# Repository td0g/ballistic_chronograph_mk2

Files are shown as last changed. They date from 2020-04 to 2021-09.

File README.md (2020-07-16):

# ballistic_chronograph_mk2

The Ballistic Chronograph MK2 is based on my earlier model, but has been redesigned for ease of assembly.  For more information, please see td0g.ca.

## Files

### LightGateSensor

The PCB design for the sensors used in the chronograph.

### STL

3D print files for the chronograph.  Make sure to print the correct files as there are options:

* Slit Width: 2mm or 3mm

* Sensor Height: Single or Double

* Sensor Width: 125mm or 100mm

### Arduino Firmware

* BallistiChronographBasic - Very basic use, can support Serial connection or LCD display.

* BallistiChronographCompound - Allows up to 6 sensors, Serial connection only.

* BallisticChronographLCD - Standalone firmware with flash triggering capability for Arduino with an LCD keypad shield.

### Assembly Manual

A complete assembly manual for constructing your own ballistic chronograph.

## License

Documentation and STL files are licensed under a [Creative Commons Attribution 4.0 International License](https://creativecommons.org/licenses/by/4.0/)

Software is licensed under a [GNU GPL v3 License](https://www.gnu.org/licenses/gpl-3.0.txt)

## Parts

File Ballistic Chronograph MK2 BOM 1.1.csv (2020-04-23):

Notes
 | Digikey is my preferred electronics vendor (Good prices, cheapest shipping, ships from Winnipeg) |  |  |  |  | Last updated 2020-04-22
 | Mouser and others are good as well. Same with eBay/Alibaba/Bangood.
 | Spool3D is my preferred hardware vendor
Part# | Manufacturer Model | Description | Qty (Single / Double Sensor Height) | Suggested Vendor | Vendor Part # | Price Per (CAD, At time of original manufacture) | Link
1 | TSHF5410 | LED (emitter) | 8 / 16 | Digikey | TSHF5410/751-1211-ND | $1.04 | https://www.digikey.ca/product-detail/en/vishay-semiconductor-opto-division/TSHF5410/751-1211-ND/1681346
2 | LG0 | Light Gate Sensors | 2 / 4 | Tindie |  | $17.70 | tindie.com
3 | Arduino Uno | Arduino | 1 | Amazon |  | $14.00 | https://www.amazon.ca/Arduino-Development-Microcontroller-Atmega328p-Straight/dp/B07M87FYPD
4 | LCD Keypad Shield | Arduino UI Shield | 1 | Amazon |  | $11.20 | https://www.amazon.ca/SODIAL-Keypad-Shield-Backlight-Arduino/dp/B00OPO2W6M
5 | 2020 Aluminum Extrusion |  | ~1m (depending on your desired size) | Spool3D |  | $12.00 | https://spool3d.ca/2020-aluminum-extrusion/
6 | PLA Plus / PETG Filament | 3D print material | ~0.5kg | Spool3D |  | $15.00 | https://spool3d.ca
7 | M2 x 8mm Screws | Fasteners | 18 / 22 |  |  | -
8 | M3 x 8mm Screws | Fasteners | 4 |  |  | -
9 | M4 x 10mm Screws | Fasteners | 12 |  |  | -
10 | M4 T-Slot Nuts | Fasteners | 12 |  |  | -
11 | Prototyping Female-Female Jumper Wires | Wiring | 10 |  |  | -
12 | 22-Gauge Wire | Wiring | ~3m |  |  | -
13 | LED Current Limiting Resistors (Please see assembly manual, appendix A) |  |  |  |  | -
 |  |  |  |  | Total Price (Single Sensor Height) | $95.92 | CAD
 |  |  |  |  | Total Price (Double Sensor Height) | $139.64 | CAD

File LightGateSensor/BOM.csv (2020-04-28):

Index | Quantity | Digikey Part Number | LCSC Part Number | Manufacturer Part Number | Description | Value | Footprint | Designator
1 | 1 | 296-12686-1-ND | C9846 | TPS61041DBVR | IC LED DRIVER RGLTR DIM SOT23-5 |  | SOT-23-5 | U2
2 | 1 | LM339MX/NOPBCT-ND | C89046 |  | IC COMPARATOR QUAD LO PWR 14SOIC |  | SOIC-14_150mil | U1
3 | 1 |  | C104352 |  | RES 470K 1/8W | 470K | 805 | R10
4 | 2 | 587-4963-1-ND | C342803 | UMK212BB7225MG-T | CAP CER 2.2UF 50V X7R 0805 | 2.2UF | 805 | C6 C7
5 | 4 |  | C76645 |  | CAP CER 1UF 50V X7R 0805 | 1UF | 805 | C1 C2 C3 C4
6 | 1 |  | C253451 |  | RES 22K 1/8W | 22K | 805 | R11
7 | 5 | A126361CT-ND | C156145 | CRG0805F330K | RES SMD 330K OHM 1% 1/8W 0805 | 330K | 805 | R2 R4 R6 R8
8 | 1 | 478-7806-1-ND | C455082 | SD1206S040S2R0 | Diode |  | SOD-123 | D5
9 | 4 | RMCF0805JT47K0CT-ND | C304417 | RMCF0805JT47K0 | RES 47K OHM 5% 1/8W 0805 | 47K | 805 | R1 R3 R5 R7
10 | 1 | 587-2985-1-ND | C106836 | TMK212BBJ106KG-T | CAP CER 10UF 16V X5R 0805 | 10UF | 805 | C5
11 | 1 | 399-7874-1-ND | C162300 | C0603C220J1GACTU | CAP CER 22PF 100V C0G/NP0 0603 | 22PF | 805 | C8
12 | 1 | 587-1613-1-ND | C223252 | CBC2518T100M | FIXED IND 10UH 680MA 468 MOHM | 22UH | 805 | L2
13 | 1 | CMP321609UD4R7MT | C139250 |  | FIXED IND 4.7UH 700mA | 4.7UH | 1206 | L1
14 | 4 | 1993-1049-ND |  | PT6KV-502A2020 | 5K Pot
15 | 4 | 160-1987-ND |  | LTR-323DB | SENSOR PHOTODIODE 900NM RADIAL
16 | 1 |  |  | lg0 | PCB

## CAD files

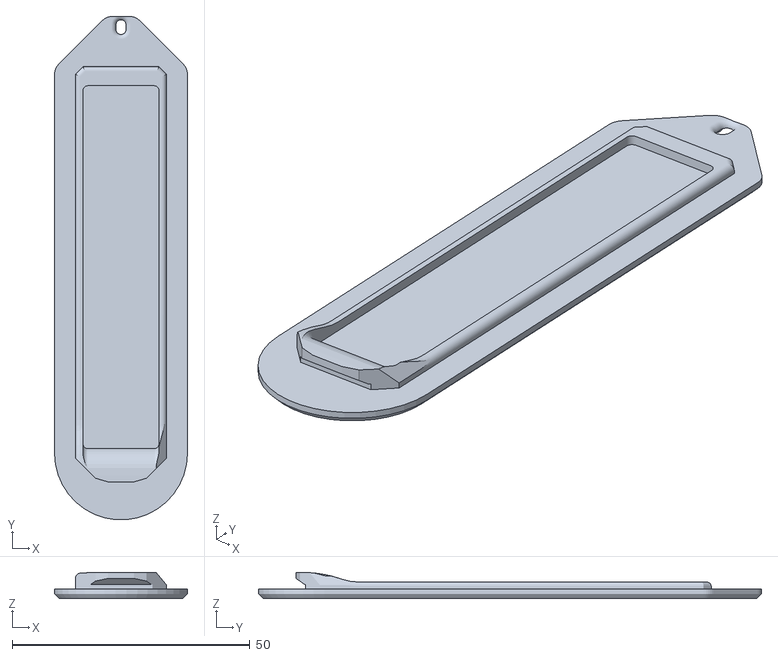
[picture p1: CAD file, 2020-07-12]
STL/EmitterCover_double.STL
28.0 x 106.0 x 5.50

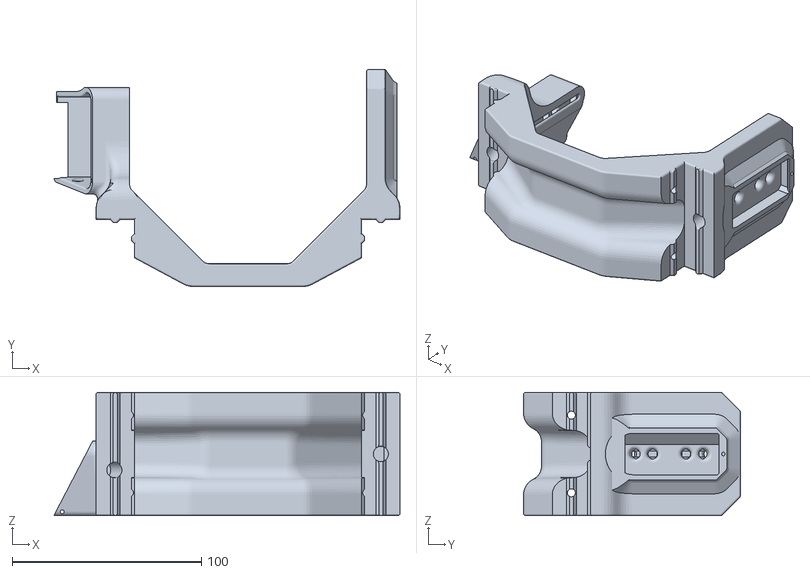
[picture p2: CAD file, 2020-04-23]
STL/Gate_single_3mmSlit_125mmWidth.STL
182.6 x 114.5 x 65.0

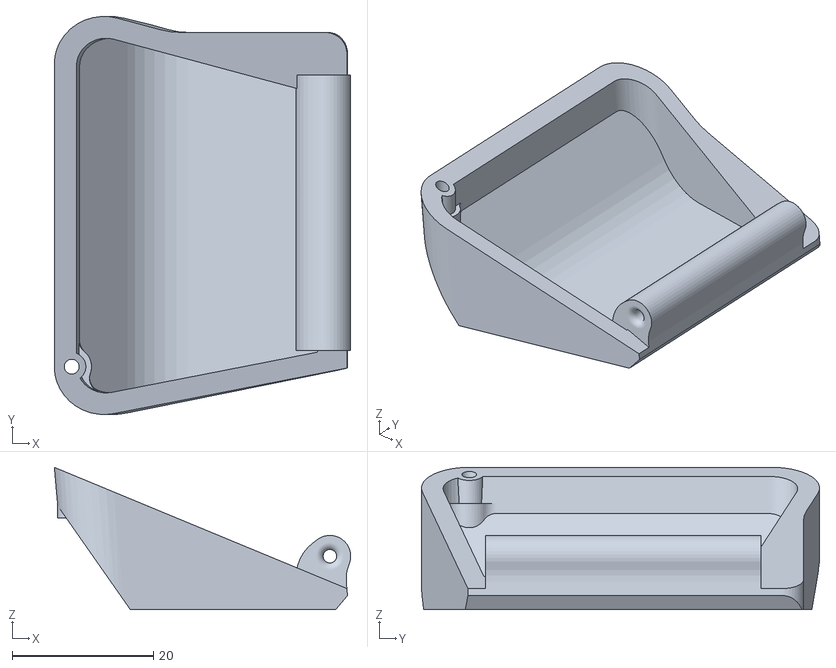
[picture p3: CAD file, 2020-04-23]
STL/SensorCover_single.STL
41.9 x 56.3 x 20.1

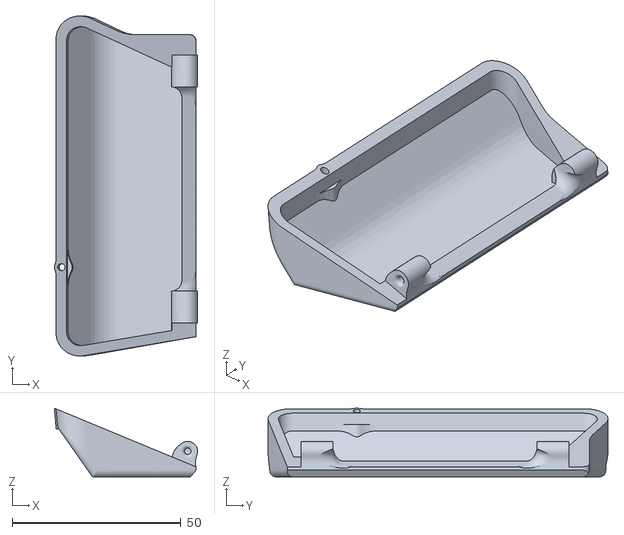
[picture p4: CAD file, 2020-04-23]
STL/SensorCover_double.STL
42.5 x 100.7 x 20.4

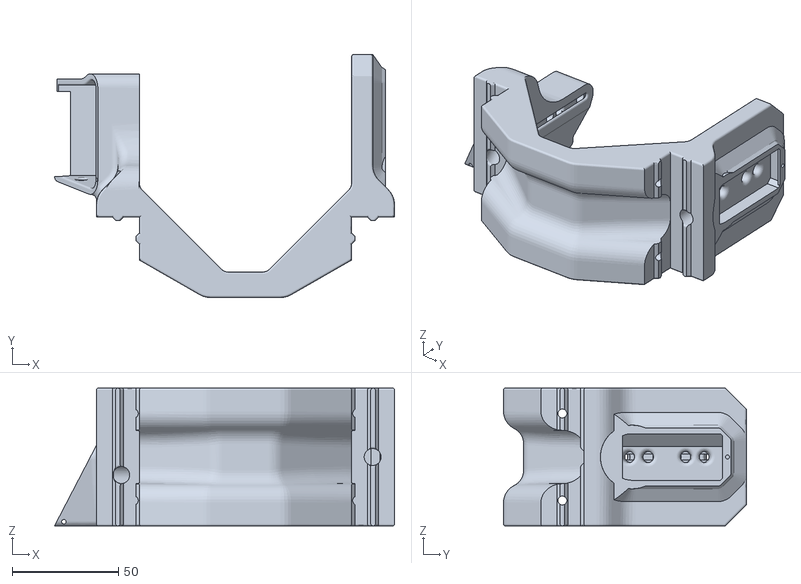
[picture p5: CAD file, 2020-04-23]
STL/Gate_single_3mmSlit_100mmWidth.STL
160.2 x 114.5 x 65.0

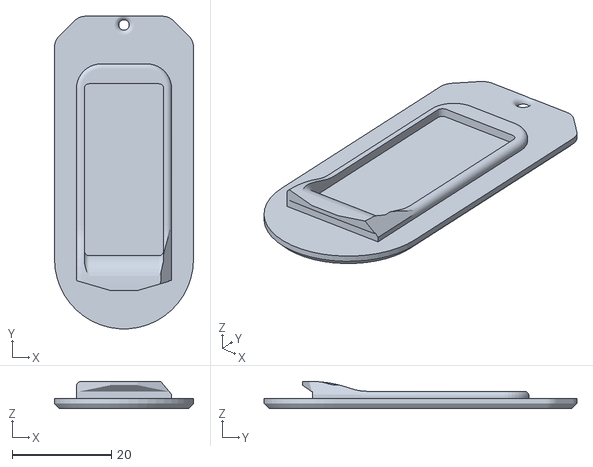
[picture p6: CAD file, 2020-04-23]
STL/EmitterCover_single.STL
28.0 x 63.0 x 5.50

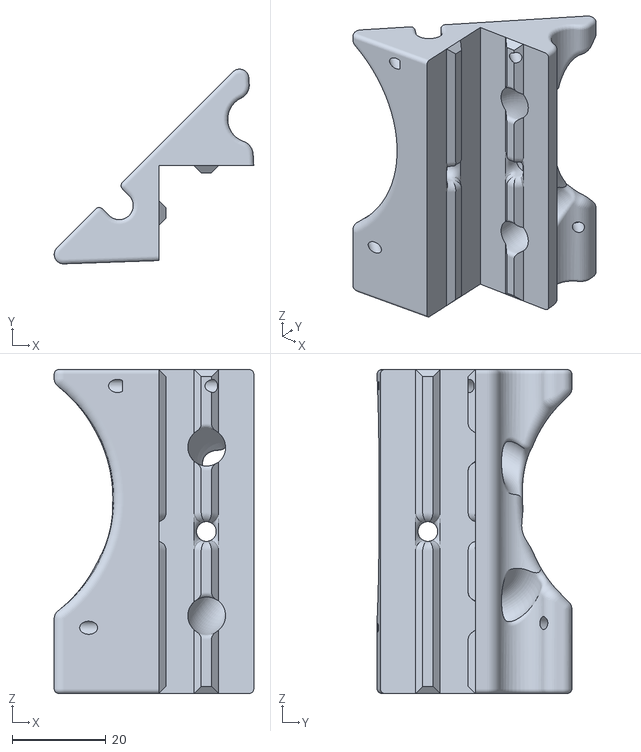
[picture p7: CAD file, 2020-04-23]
STL/Arduino Mount.STL
42.5 x 41.5 x 69.0

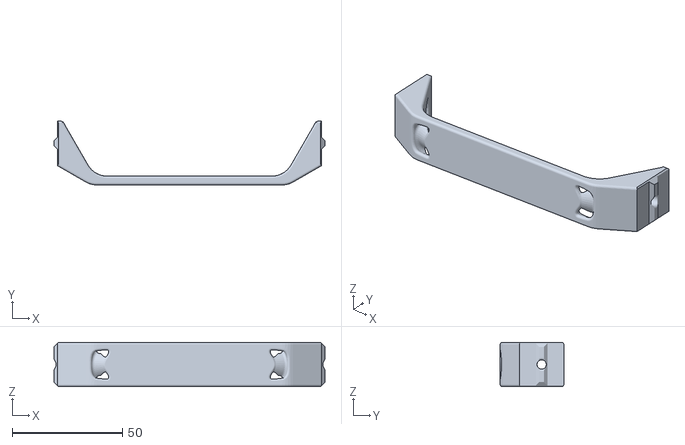
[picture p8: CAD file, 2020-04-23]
STL/Crossmember.STL
123.0 x 29.0 x 20.0

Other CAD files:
STL/Gate_single_2mmSlit_125mmWidth.STL
STL/Gate_single_2mmSlit_100mmWidth.STL

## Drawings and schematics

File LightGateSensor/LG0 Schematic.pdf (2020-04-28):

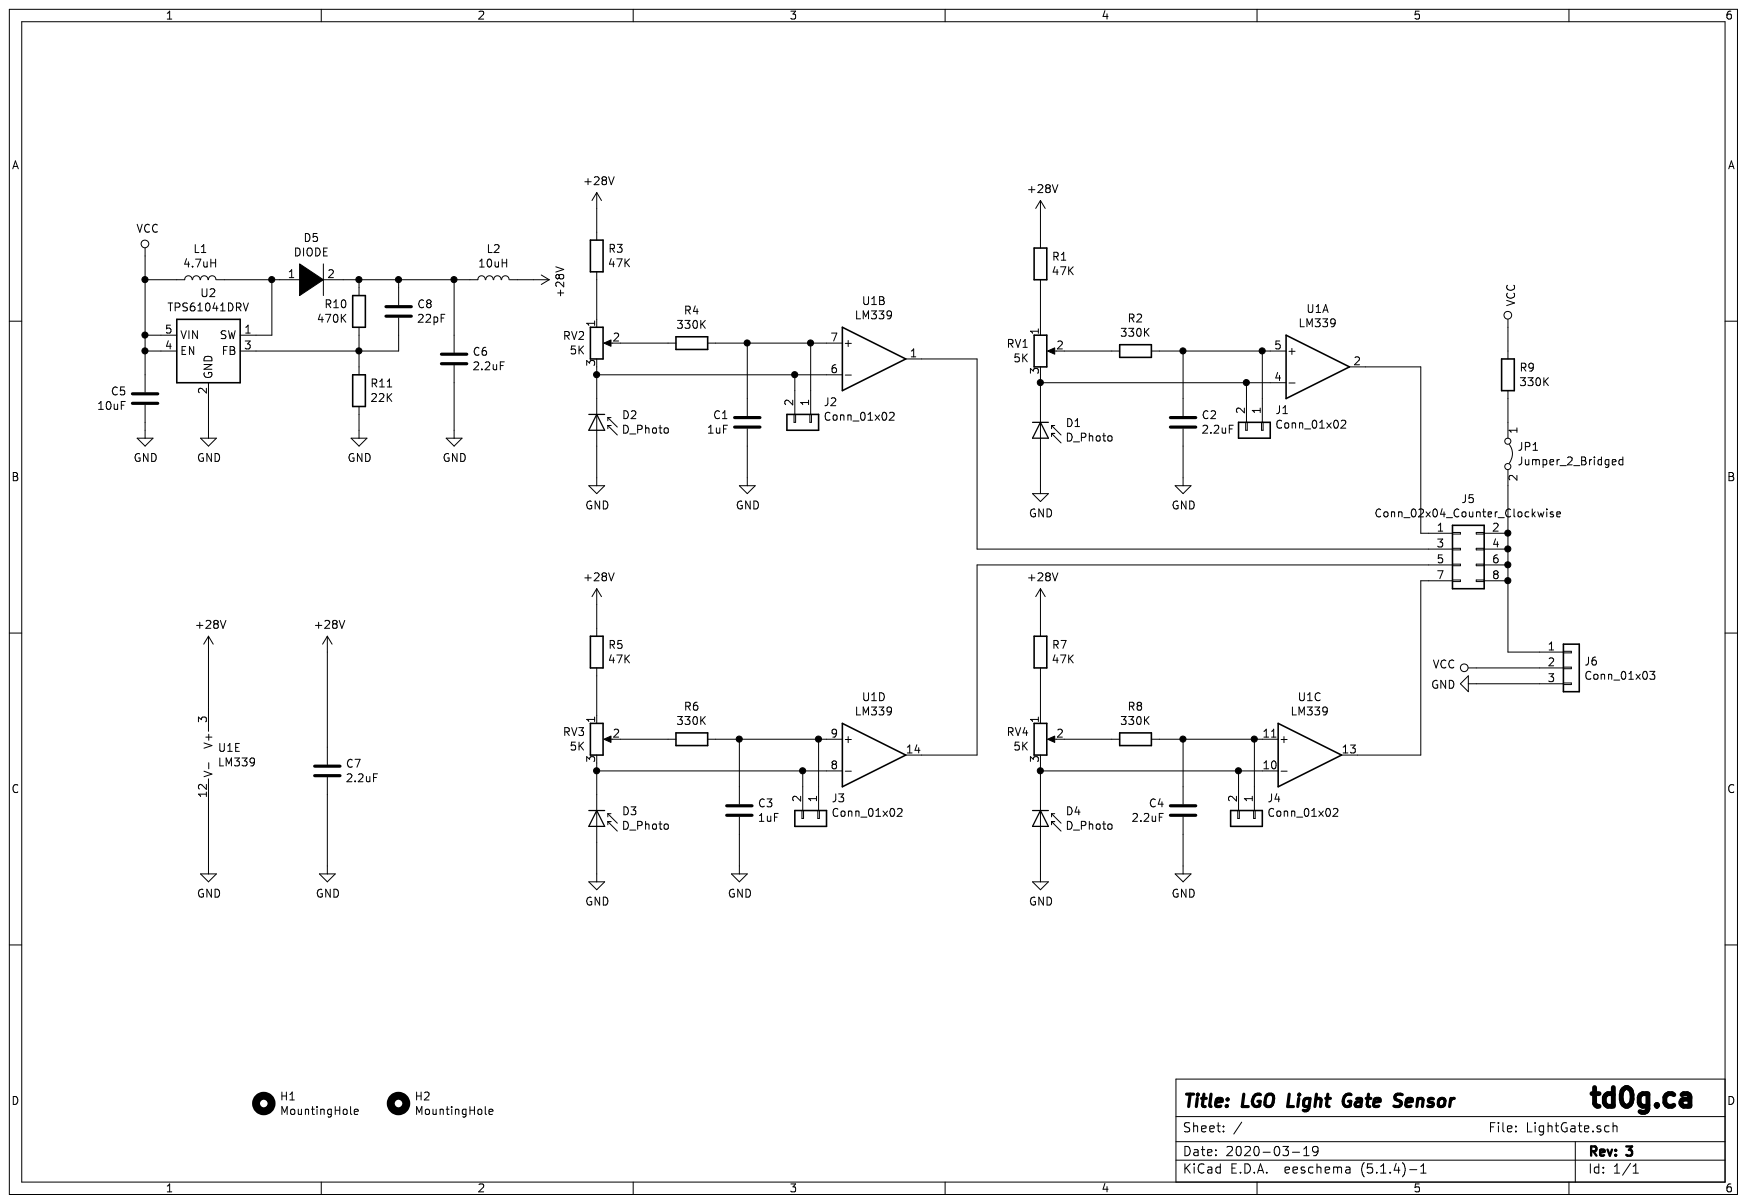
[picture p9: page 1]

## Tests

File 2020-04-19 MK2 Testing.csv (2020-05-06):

TEST | MK1 | MK1 (Adjusted for Clock Error) | MK2 | Error | Notes
TEST SET 1 (CO2 Airsoft Pistol)
1 | 104.81 | 102.96 | 107.33 | 4.25%
2 | 104.11 | 102.27 | 106.63 | 4.26%
3 | 106.04 | 104.17 | 108.3 | 3.97%
4 | 102.23 | 100.42 | 104.34 | 3.90%
5 | 102.15 | 100.34 | 104.48 | 4.12%
6 | 105.75 | 103.88 | 107.99 | 3.96%
7 | 108.94 | 107.01 | 111.48 | 4.17%
8 | 106.21 | 104.33 | 108.79 | 4.27%
9 | 106.15 | 104.27 | 108.34 | 3.90%
10 | 101.68 | 99.88 | 103.91 | 4.03%
TEST SET 2 (CO2 Airsoft Pistol, Chronographs Swapped)
1 | 108.75 | 106.83 | 103.62 | -3.00% | Chronographs swapped (MK1 then MK2)
2 | 107.45 | 105.55 | 102.3 | -3.08% | Chronographs swapped (MK1 then MK2)
3 | 105.8 | 103.93 | 100.8 | -3.01% | Chronographs swapped (MK1 then MK2)
4 | 110.02 | 108.07 | 104.96 | -2.88% | Chronographs swapped (MK1 then MK2)
5 | 111.19 | 109.22 | 105.96 | -2.99% | Chronographs swapped (MK1 then MK2)
6 | 111.25 | 109.28 | 106 | -3.00% | Chronographs swapped (MK1 then MK2)
7 | 110.33 | 108.38 | 105.06 | -3.06% | Chronographs swapped (MK1 then MK2)
8 | 111.07 | 109.11 | 105.64 | -3.18% | Chronographs swapped (MK1 then MK2)
9 | 108.28 | 106.37 | 102.94 | -3.22% | Chronographs swapped (MK1 then MK2)
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

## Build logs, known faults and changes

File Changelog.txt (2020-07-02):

Rev0
	Initial Release
Rev 1
	Adjusted design to use the same length fasteners for each size (8mm M2, 8mm M3, 10mm M4)
	Angled top and bottom photodiodes and LED's slightly for better signal
	Improved the Double-Height sensor door
	
Rev2
	Changed double-height models to allow light from bottom LED's to reach top photodiodes (and vice versa)

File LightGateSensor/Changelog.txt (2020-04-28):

Rev 1
	Port to KiCad

Rev 2
	Added inductor to boost converter outyput
	Boost converter inductor changed to 4.7uH
	Biasing caps changed to 1uF

Rev 3
	Corrected GND/SIG labels on top layer

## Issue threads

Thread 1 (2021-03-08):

Part Sourcing

bmartin598, 2021-03-08:
Hello,

I am working on sourcing parts for the Lightgate PCB. The Schottky Barrier Diode you have in the BOM pulls up two different ones. Your digikey and manufacturer part number return 1 diode (which has been discontinued) and your LCSC part number pulls up a different one. Will the LCSC part work? It has a different package call out and don't know if it would fit.

Thanks

TheAxeDude, 2023-03-10:
@bmartin598  what was your resolution here? Doing the same thing now

Closed 2021-03-10.

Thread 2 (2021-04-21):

None of the 3 functions are working

bmartin598, 2021-04-21:
After downloading the code I attempted to compile it onto the arduino. Compound and Basic both are erroring out with "TCCR1A was not declared in this scope" and LCD is erroring out with "PINC was not declared in this scope"

bmartin598, 2021-05-07:
Arduino Uno Rev 2 has a different microcontroller. This caused the issues. Uno Rev 1 and Rev 3 work.

Closed 2021-05-07.

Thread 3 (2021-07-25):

LG0_rev3_datasheet.pdf anode/cathode issue

dbgarlisch, 2021-07-25:
At the bottom of page 2:

> The photodiode are oriented with the _**anode (longer lead) adjacent to the edge**_ and the _**cathode (shorter
> lead) next to the potentiometers**_.

However, I believe the text describes the opposite of what is shown in the image below it. Which is correct?

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

dezanche, 2023-01-16:
Sometimes the lead lengths are the opposite (long = cathode). I found that the flat edge at the base of the LED is a more reliable indicator of the cathode. The best is to check with a multimeter.

td0g, 2023-01-17:
The image actually shows the photodiodes with the longer leg bent, so at first glance it may look like it's installed in reverse.  There should be a note clarifying this, thanks for pointing it out.

**dezanche** - The [datasheet for the LTR323DB](https://www.mouser.ca/datasheet/2/239/R323DB-1141936.pdf) indicates the anode will have a longer leg.  Have you found this to be untrue with the LTR323DB, or just on other photodiodes?

dezanche, 2023-01-17:
I was speaking generally. I noticed this for LEDs, and it may be true for photodiodes as well. I haven't tried building this device.

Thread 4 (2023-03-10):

LightGateSensor missing R9 designator from BOM

TheAxeDude, 2023-03-10:
Im fairly new to getting PCBs manufactured, and had a few of the LG0 made up. I noticed a spot on the PCB for R9 - which hasnt been populated in the BOM. Looking at the schematic, it should be the same as R1- R8.

Can anyone confirm if this is correct?

dezanche, 2023-03-13:
R9 is the pull-up resistor, which is needed unless you cut the JP1 jumper. I didn't find a specific explanation of why you might need to do this. Two possibilities are if that pull-up resistor is present elsewhere (e.g., on the Arduino or other board you use to measure the transit time between light gates), or if you're using multiple LG0 boards in parallel to increase the viewing window (in which case only one is needed and if you didn't cut it the combined resistance would be half = 330k/2 ohm).
Hope this helps.

TheAxeDude, 2023-03-23:
@dezanche thank you for pointing that out, it seems to make sense. Ill post-back if I figure out more, or manage to get to a working state.

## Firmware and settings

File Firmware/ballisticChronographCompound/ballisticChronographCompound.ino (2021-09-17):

/*
  Firmware for Ballistic Chronograph
  Written by Tyler Gerritsen
  vtgerritsen@gmail.com
  www.td0g.ca

DESCRIPTION:
  Basic firmware for an Arduino-based ballistic chronograph with 2 - 6 gates.  Connect the Arduino to a PC and it will automatically read out the speed.  
  This firmware uses Timer1 to measure the time between gate transits.
  This firmware is optimized for high-speed testing and the minimum gate to gate time is 14 microseconds

CHANGELOG:
1.0
  2020-07-04
  Initial Release
1.1
  2020-07-16
  Using watchdog timer for timeout function, this improves sampling speed
  Added individual gate separation override

1.2
  2020-07-21
  Improvements to interrupt disabling function
  Added acceleration calucations
  Added string-printing and integer-printing function for interurpt routine (easier to read code)
  Optimized watchdog serial speed
  Improved code readability
  
1.3
  2021-06-25
  Increased maximum gates from 6 to 16
  Added diagnostics check to beginning of routine

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
  You should have received a copy of the GNU General Public License
  along with this program.  If not, see <https://www.gnu.org/licenses/>.
 */






//SETUP ####################################################################################
//Definitions - PLEASE SET UP BEFORE USING

 //Serial port baud rate
#define BAUD 9600       

//Default distance in mm between each pair of gates (NOT the entire length of multi-sensor array).  This distance can be overwritten by the individual gate separations below.
#define GATE_SEPARATION_DEFAULT 287.0 

//Override the individual gate separations here (OPTIONAL)
#define GATE_AB_SEPARATION 286.9
#define GATE_BC_SEPARATION 573.4-286.9
#define GATE_CD_SEPARATION 860.7-573.4
#define GATE_DE_SEPARATION 1146.6-860.7
#define GATE_EF_SEPARATION 1136.4-848.6
#define GATE_FG_SEPARATION 1136.4-848.6
#define GATE_GH_SEPARATION 1136.4-848.6
#define GATE_HI_SEPARATION 1136.4-848.6
#define GATE_IJ_SEPARATION 1136.4-848.6
#define GATE_JK_SEPARATION 1136.4-848.6
#define GATE_KL_SEPARATION 1136.4-848.6
#define GATE_LM_SEPARATION 1136.4-848.6
#define GATE_MN_SEPARATION 1136.4-848.6
#define GATE_NO_SEPARATION 1136.4-848.6
//#define GATE_OP_SEPARATION 1136.4-848.6

//Enter the Arduino pin of the sensor input.  For A0, use 14.  A1, use 15. A2, use 16.  A3, use 17.  A4, use 18.  A5, use 19.  Gates A and B required.  Gates C through P are optional.
#define GATE_A_PIN 14
#define GATE_B_PIN 15
#define GATE_C_PIN 16
#define GATE_D_PIN 17
#define GATE_E_PIN 18
#define GATE_F_PIN 19
//#define GATE_G_PIN 19
//#define GATE_H_PIN 19
//#define GATE_I_PIN 19
//#define GATE_J_PIN 19
//#define GATE_K_PIN 19
//#define GATE_L_PIN 19
//#define GATE_M_PIN 19
//#define GATE_N_PIN 19
//#define GATE_O_PIN 19
//#define GATE_P_PIN 19

//Active low means 0V is a gate trigger.  COMMENT OUT for active high (5V = gate is triggered). 
#define ACTIVE_LOW    

//Gate pins are pulled up.  COMMENT OUT to disable pullup resistors.
//#define PULLUP              

//Milliseconds between each gate before test resets. Valid values = 16, 32, 64, 125, 250, 500, 1000, 2000, 4000, 8000
//Note that this will limit the time to output Serial data.  Use BAUD 57600 or higher if MAX_TRANSIT_TIME is less than 64.
#define MAX_TRANSIT_TIME 1000

//Number of times to perform diagnostics check before each test.  COMMENT OUT to disable check
#define DIAGNOSTICS_CHECKS 100000

//END OF SETUP ##############################################################################






//Other files
  #include <avr/wdt.h>
  #include "defs.h"
  
//Declare variables
  unsigned int testIndex = 0;
  const float mTOf = 3.280;
  float gateSeparation[GATE_COUNT - 1] = GATE_SEPARATION_ARRAY;
  volatile byte ovfCount;
  volatile unsigned long testTimes[GATE_COUNT-1];
  volatile unsigned long testTime1; //This is the timer count
  volatile unsigned long testOvf1;  //This is the timer overflow count
  #ifdef GATE_C_PIN
    volatile unsigned long testTime2;
    volatile unsigned long testOvf2;
    #ifdef GATE_D_PIN
      volatile unsigned long testTime3;
      volatile unsigned long testOvf3;
      #ifdef GATE_E_PIN
        volatile unsigned long testTime4;
        volatile unsigned long testOvf4;
        #ifdef GATE_F_PIN
          volatile unsigned long testTime5;
          volatile unsigned long testOvf5;
          #ifdef GATE_G_PIN
            volatile unsigned long testTime6;
            volatile unsigned long testOvf6;
            #ifdef GATE_H_PIN
              volatile unsigned long testTime7;
              volatile unsigned long testOvf7;
              #ifdef GATE_I_PIN
                volatile unsigned long testTime8;
                volatile unsigned long testOvf8;
                #ifdef GATE_J_PIN
                  volatile unsigned long testTime9;
                  volatile unsigned long testOvf9;
                  #ifdef GATE_K_PIN
                    volatile unsigned long testTime10;
                    volatile unsigned long testOvf10;
                    #ifdef GATE_L_PIN
                      volatile unsigned long testTime11;
                      volatile unsigned long testOvf11;
                      #ifdef GATE_M_PIN
                        volatile unsigned long testTime12;
                        volatile unsigned long testOvf12;
                        #ifdef GATE_N_PIN
                          volatile unsigned long testTime13;
                          volatile unsigned long testOvf13;
                          #ifdef GATE_O_PIN
                            volatile unsigned long testTime14;
                            volatile unsigned long testOvf14;
                            #ifdef GATE_P_PIN
                              volatile unsigned long testTime15;
                              volatile unsigned long testOvf15;
                            #endif
                          #endif
                        #endif
                      #endif
                    #endif
                  #endif
                #endif
              #endif
            #endif
          #endif
        #endif
      #endif
    #endif
  #endif
  #define TAB Serial.print(F("\t")); Serial.print(F("\t"))
  
void setup() {
//Setup pin states
  setPinStates();

//Setup timer1
  TCCR1A = 0; //No pin changes needed
  TCCR1B = (TCCR1B & 0b11100000) | 0b00000010;         // div8 = 1/2us per increment, 16-bit normal mode
  TIMSK1 |= 1;  //Turn on overflow interrupt
  
//Start communicating with PC
  Serial.begin(BAUD);   
  Serial.println("\n\nBallistic Chronograph - READY");  //Hello world message
  Serial.print(F("Max transit time per gate: "));
  Serial.print(MAX_TRANSIT_TIME);
  Serial.println(F(" ms"));

  delay(100);
}

void loop(){
  runDiagnostics();
  
//Reset variables
  testTime1 = 0;
  testOvf1 = 0;
  for (byte i = 0; i < GATE_COUNT; i++) testTimes[i] = 0;
  
//Turn off interrupts so that the microcontroller can focus on watching the gates
  disableInterrupts();
    
//Wait until GATE A gives a signal
  while (GATE_A) {};
  
//Reset Timer1 counter and overflow counter to 0
  TCNT1 = 0;
  ovfCount = 0;
  testTimes[0] = 0;

//Turn on the watchdog timer
  cli();
  wdt_reset();
  WDTCSR |= (1<<WDCE) | (1<<WDE);
  WDTCSR = WDT_ON;
  sei();
  wdt_reset();

//Wait until each successive gate gives a signal OR timeout happens.  If timeout happened, just end test.
  while(GATE_B) {};
  testTime1 = TCNT1;
  testOvf1 = ovfCount;
  wdt_reset();
  testOvf1 = testOvf1 << 16;
  testTime1 += testOvf1;
  testTimes[1] = testTime1;

  #ifdef GATE_C_PIN
    testTime2 = 0;
    testOvf2 = 0;
    while(GATE_C) {};
    testTime2 = TCNT1;
    testOvf2 = ovfCount;
    wdt_reset();
    testOvf2 = testOvf2 << 16;
    testTime2 += testOvf2;
    testTimes[2] = testTime2;
    
    #ifdef GATE_D_PIN
      testTime3 = 0;
      testOvf3 = 0;
      while(GATE_D_PIN2) {};
      testTime3 = TCNT1;
      testOvf3 = ovfCount;
      wdt_reset();
      testOvf3 = testOvf3 << 16;
      testTime3 += testOvf3;
      testTimes[3] = testTime3;
      
      #ifdef GATE_E_PIN
        testTime4 = 0;
        testOvf4 = 0;
        while(GATE_E_PIN2) {};
        testTime4 = TCNT1;
        testOvf4 = ovfCount;
        wdt_reset();
        testOvf4 = testOvf4 << 16;
        testTime4 += testOvf4;
        testTimes[4] = testTime4;
        
        #ifdef GATE_F_PIN
          testTime5 = 0;
          testOvf5 = 0;
          while(GATE_F_PIN2) {};
          testTime5 = TCNT1;
          testOvf5 = ovfCount;
          wdt_reset();
          testOvf5 = testOvf5 << 16;
          testTime5 += testOvf5;
          testTimes[5] = testTime5;
        
          #ifdef GATE_G_PIN
            testTime6 = 0;
            testOvf6 = 0;
            while(GATE_G_PIN2) {};
            testTime6 = TCNT1;
            testOvf6 = ovfCount;
            wdt_reset();
            testOvf6 = testOvf6 << 16;
            testTime6 += testOvf6;
            testTimes[6] = testTime6;
        
            #ifdef GATE_H_PIN
              testTime7 = 0;
              testOvf7 = 0;
              while(GATE_H_PIN2) {};
              testTime7 = TCNT1;
              testOvf7 = ovfCount;
              wdt_reset();
              testOvf7 = testOvf7 << 16;
              testTime7 += testOvf7;
              testTimes[7] = testTime7;
        
              #ifdef GATE_I_PIN
                testTime8 = 0;
                testOvf8 = 0;
                while(GATE_I_PIN2) {};
                testTime8 = TCNT1;
                testOvf8 = ovfCount;
                wdt_reset();
                testOvf8 = testOvf8 << 16;
                testTime8 += testOvf8;
                testTimes[8] = testTime8;
        
                #ifdef GATE_J_PIN
                  testTime9 = 0;
                  testOvf9 = 0;
                  while(GATE_J_PIN2) {};
                  testTime9 = TCNT1;
                  testOvf9 = ovfCount;
                  wdt_reset();
                  testOvf9 = testOvf9 << 16;
                  testTime9 += testOvf9;
                  testTimes[9] = testTime9;
        
                  #ifdef GATE_K_PIN
                    testTime10 = 0;
                    testOvf10 = 0;
                    while(GATE_K_PIN2) {};
                    testTime10 = TCNT1;
                    testOvf10 = ovfCount;
                    wdt_reset();
                    testOvf10 = testOvf10 << 16;
                    testTime10 += testOvf10;
                    testTimes[10] = testTime10;
                    
                    #ifdef GATE_L_PIN
                      testTime11 = 0;
                      testOvf11 = 0;
                      while(GATE_L_PIN2) {};
                      testTime11 = TCNT1;
                      testOvf11 = ovfCount;
                      wdt_reset();
                      testOvf11 = testOvf11 << 16;
                      testTime11 += testOvf11;
                      testTimes[11] = testTime11;
        
                      #ifdef GATE_M_PIN
                        testTime12 = 0;
                        testOvf12 = 0;
                        while(GATE_M_PIN2) {};
                        testTime12 = TCNT1;
                        testOvf12 = ovfCount;
                        wdt_reset();
                        testOvf12 = testOvf12 << 16;
                        testTime12 += testOvf12;
                        testTimes[12] = testTime12;
        
                        #ifdef GATE_N_PIN
                          testTime13 = 0;
                          testOvf13 = 0;
                          while(GATE_N_PIN2) {};
                          testTime13 = TCNT1;
                          testOvf13 = ovfCount;
                          wdt_reset();
                          testOvf13 = testOvf13 << 16;
                          testTime13 += testOvf13;
                          testTimes[13] = testTime13;
                          
                          #ifdef GATE_O_PIN
                            testTime14 = 0;
                            testOvf14 = 0;
                            while(GATE_O_PIN2) {};
                            testTime14 = TCNT1;
                            testOvf14 = ovfCount;
                            wdt_reset();
                            testOvf14 = testOvf14 << 16;
                            testTime14 += testOvf14;
                            testTimes[14] = testTime14;
        
                            #ifdef GATE_P_PIN
                              testTime15 = 0;
                              testOvf15 = 0;
                              while(GATE_P_PIN2) {};
                              testTime15 = TCNT1;
                              testOvf15 = ovfCount;
                              wdt_reset();
                              testOvf15 = testOvf15 << 16;
                              testTime15 += testOvf15;
                              testTimes[15] = testTime15;
                            #endif
                          #endif
                        #endif
                      #endif
                    #endif
                  #endif
                #endif
              #endif
            #endif
          #endif
        #endif
      #endif
    #endif
  #endif
  
//Disable watchdog timer
  cli();
  WDTCSR |= (1<<WDCE) | (1<<WDE);
  WDTCSR = 0;
  sei();
  
//Enable interrupts so that Serial functions work
  enableInterrupts();

//Display stats
  printStats();
  }


ISR(TIMER1_OVF_vect) {ovfCount++;}

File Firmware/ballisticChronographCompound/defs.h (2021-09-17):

//Pin Selection Definitions
  #if (GATE_A_PIN == 2)
    #define GATE_A_PIN2 (PIND & 0b00000100)
  #elif (GATE_A_PIN == 3)
    #define GATE_A_PIN2 (PIND & 0b00001000)
  #elif (GATE_A_PIN == 4)
    #define GATE_A_PIN2 (PIND & 0b00010000)
  #elif (GATE_A_PIN == 5)
    #define GATE_A_PIN2 (PIND & 0b00100000)
  #elif (GATE_A_PIN == 6)
    #define GATE_A_PIN2 (PIND & 0b01000000)
  #elif (GATE_A_PIN == 7)
    #define GATE_A_PIN2 (PIND & 0b10000000)
  #elif (GATE_A_PIN == 8)
    #define GATE_A_PIN2 (PINB & 0b00000001)
  #elif (GATE_A_PIN == 9)
    #define GATE_A_PIN2 (PINB & 0b00000010)
  #elif (GATE_A_PIN == 10)
    #define GATE_A_PIN2 (PINB & 0b00000100)
  #elif (GATE_A_PIN == 11)
    #define GATE_A_PIN2 (PINB & 0b00001000)
  #elif (GATE_A_PIN == 12)
    #define GATE_A_PIN2 (PINB & 0b00010000)
  #elif (GATE_A_PIN == 13)
    #define GATE_A_PIN2 (PINB & 0b00100000)
  #elif (GATE_A_PIN == 14)
    #define GATE_A_PIN2 (PINC & 0b00000001)
  #elif (GATE_A_PIN == 15)
    #define GATE_A_PIN2 (PINC & 0b00000010)
  #elif (GATE_A_PIN == 16)
    #define GATE_A_PIN2 (PINC & 0b00000100)
  #elif (GATE_A_PIN == 17)
    #define GATE_A_PIN2 (PINC & 0b00001000)
  #elif (GATE_A_PIN == 18)
    #define GATE_A_PIN2 (PINC & 0b00010000)
  #elif (GATE_A_PIN == 19)
    #define GATE_A_PIN2 (PINC & 0b00100000)
  #else
    #error "You must set Gate A to a valid pin!  Use 14 for A0, 15 for A1, and so on..."
  #endif

  #ifdef ACTIVE_LOW
    #define GATE_A GATE_A_PIN2
  #else
    #define GATE_A !GATE_A_PIN2
  #endif

  #ifndef GATE_AB_SEPARATION
    #define GATE_AB_SEPARATION GATE_SEPARATION_DEFAULT
  #endif
          
  #if (GATE_B_PIN == 2)
    #define GATE_B_PIN2 (PIND & 0b00000100)
  #elif (GATE_B_PIN == 3)
    #define GATE_B_PIN2 (PIND & 0b00001000)
  #elif (GATE_B_PIN == 4)
    #define GATE_B_PIN2 (PIND & 0b00010000)
  #elif (GATE_B_PIN == 5)
    #define GATE_B_PIN2 (PIND & 0b00100000)
  #elif (GATE_B_PIN == 6)
    #define GATE_B_PIN2 (PIND & 0b01000000)
  #elif (GATE_B_PIN == 7)
    #define GATE_B_PIN2 (PIND & 0b10000000)
  #elif (GATE_B_PIN == 8)
    #define GATE_B_PIN2 (PINB & 0b00000001)
  #elif (GATE_B_PIN == 9)
    #define GATE_B_PIN2 (PINB & 0b00000010)
  #elif (GATE_B_PIN == 10)
    #define GATE_B_PIN2 (PINB & 0b00000100)
  #elif (GATE_B_PIN == 11)
    #define GATE_B_PIN2 (PINB & 0b00001000)
  #elif (GATE_B_PIN == 12)
    #define GATE_B_PIN2 (PINB & 0b00010000)
  #elif (GATE_B_PIN == 13)
    #define GATE_B_PIN2 (PINB & 0b00100000)
  #elif (GATE_B_PIN == 14 || GATE_B_PIN == A0)
    #define GATE_B_PIN2 (PINC & 0b00000001)
  #elif (GATE_B_PIN == 15 || GATE_B_PIN == A1)
    #define GATE_B_PIN2 (PINC & 0b00000010)
  #elif (GATE_B_PIN == 16 || GATE_B_PIN == A2)
    #define GATE_B_PIN2 (PINC & 0b00000100)
  #elif (GATE_B_PIN == 17 || GATE_B_PIN == A3)
    #define GATE_B_PIN2 (PINC & 0b00001000)
  #elif (GATE_B_PIN == 18 || GATE_B_PIN == A4)
    #define GATE_B_PIN2 (PINC & 0b00010000)
  #elif (GATE_B_PIN == 19 || GATE_B_PIN == A5)
    #define GATE_B_PIN2 (PINC & 0b00100000)
  #else
    #error "You must set Gate B to a valid pin!  Use 14 for A0, 15 for A1, and so on..."
  #endif

  #ifdef ACTIVE_LOW
    #define GATE_B GATE_B_PIN2
  #else
    #define GATE_B !GATE_B_PIN2
  #endif
  
  #ifdef GATE_C_PIN
    #ifndef GATE_BC_SEPARATION
      #define GATE_BC_SEPARATION GATE_SEPARATION_DEFAULT
    #endif
    #if (GATE_C_PIN == 2)
      #define GATE_C_PIN2 (PIND & 0b00000100)
    #elif (GATE_C_PIN == 3)
      #define GATE_C_PIN2 (PIND & 0b00001000)
    #elif (GATE_C_PIN == 4)
      #define GATE_C_PIN2 (PIND & 0b00010000)
    #elif (GATE_C_PIN == 5)
      #define GATE_C_PIN2 (PIND & 0b00100000)
    #elif (GATE_C_PIN == 6)
      #define GATE_C_PIN2 (PIND & 0b01000000)
    #elif (GATE_C_PIN == 7)
      #define GATE_C_PIN2 (PIND & 0b10000000)
    #elif (GATE_C_PIN == 8)
      #define GATE_C_PIN2 (PINB & 0b00000001)
    #elif (GATE_C_PIN == 9)
      #define GATE_C_PIN2 (PINB & 0b00000010)
    #elif (GATE_C_PIN == 10)
      #define GATE_C_PIN2 (PINB & 0b00000100)
    #elif (GATE_C_PIN == 11)
      #define GATE_C_PIN2 (PINB & 0b00001000)
    #elif (GATE_C_PIN == 12)
      #define GATE_C_PIN2 (PINB & 0b00010000)
    #elif (GATE_C_PIN == 13)
      #define GATE_C_PIN2 (PINB & 0b00100000)
    #elif (GATE_C_PIN == 14)
      #define GATE_C_PIN2 (PINC & 0b00000001)
    #elif (GATE_C_PIN == 15)
      #define GATE_C_PIN2 (PINC & 0b00000010)
    #elif (GATE_C_PIN == 16)
      #define GATE_C_PIN2 (PINC & 0b00000100)
    #elif (GATE_C_PIN == 17)
      #define GATE_C_PIN2 (PINC & 0b00001000)
    #elif (GATE_C_PIN == 18)
      #define GATE_C_PIN2 (PINC & 0b00010000)
    #elif (GATE_C_PIN == 19)
      #define GATE_C_PIN2 (PINC & 0b00100000)
    #else
      #error "You must set Gate C to a valid pin!  Use 14 for A0, 15 for A1, and so on..."
    #endif
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

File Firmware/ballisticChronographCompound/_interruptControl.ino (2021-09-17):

void disableInterrupts(){
  editInterrupts(0);
}

void enableInterrupts(){
  editInterrupts(1);
}

void enableSerial(){
  editInterrupts(2);
}

void editInterrupts(byte _s){
  //0 = All interrupts OFF
  //1 = All interrupts ON
  //2 = Turn on Serial
  static byte _tccr0b;
  static byte _tccr2b;
  static byte _spcr;
  static byte _ucsr0b;
  static byte _adcsra;
  static byte _adcsrb;
  static byte _acsr;
  static byte _eimsk;
  static byte _intState = 1;
  if (!_s){
    if (_intState){
      _intState = 0;
      _tccr0b = TCCR0B;
      _tccr2b = TCCR2B;
      _spcr = SPCR;
      _adcsra = ADCSRA;
      _adcsrb = ADCSRB;
      _acsr = ACSR;
      _eimsk = EIMSK;
      TCCR0B = 0;
      TCCR2B = 0;
      SPCR = 0;
      ADCSRA = 0;
      ADCSRB = 0;
      ACSR = 0b10000000;
      EIMSK = 0b00000000;
    }
    if (UCSR0B){
      _ucsr0b = UCSR0B;
      UCSR0B = 0; //Need to reset this for the interrupt serial
    }
  }
  else if (_s == 1 && !_intState) {
    _intState = 1;
    TCCR0B = _tccr0b;
    TCCR2B = _tccr2b;
    SPCR = _spcr;
    UCSR0B = _ucsr0b;
    ADCSRA = _adcsra;
    ADCSRB = _adcsrb;
    ACSR = _acsr;
    EIMSK = _eimsk;
  }
  else if (_s == 2 && !_intState){
    if (!_intState) UCSR0B = _ucsr0b;
  }
}

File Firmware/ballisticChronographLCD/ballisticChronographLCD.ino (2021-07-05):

/*
  Firmware for Ballistic Chronograph
  Written by Tyler Gerritsen
  tyler@td0g.ca
  www.td0g.ca

DESCRIPTION:
  Basic firmware for an Arduino-based ballistic chronograph with 2 - 6 gates.  Connect the Arduino to a PC and it will automatically read out the speed.  
  This firmware uses Timer1 to measure the time between gate transits.
  This firmware is optimized for high-speed testing and the minimum gate to gate time is 14 microseconds

CHANGELOG:
1.0 2018-01-01
  Functional
  
1.1 2020-04-15
  Added Clock Calibration screen

1.2 2020-05-06
  Fixed clock calibration bug
  Displays gate separation in calibration screen

1.3 2020-06-05
  Switched to timer1 usage

1.4 2021-06-26
  Code not working previously due to couple bugs, major fixes
  New menu structure (Settings sub-menu)
  Fewer hard-coded settings, setup possible through EEPROM settings

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
*/

/*
 Commands:

  g         Run SpeedTest
  d         Set distance to target
  pX tX     Set trigger on pin with tX microseconds preTrig
  pX tX h1  Set trigger on pin with tX microseconds preTrig, compatible with td0g high-speed flash
  rX        Remove trigger
  f         Live Feed
  b         Toggle backlight
  h         Help
  t         Fire flashes
  yXXX      Set test minimum speed in m/s
  zXXX      Set test timeout in seconds
 */




//SETUP ####################################################################################
//Definitions - PLEASE SET UP BEFORE USING

 //Serial port baud rate
#define BAUD 9600  

#define BUTTON_DEBOUNCE 300
#define GATE_SEPARATION_DEFAULT 385 //385
#define TEST_MIN_SPEED 0.1
#define TEST_MAX_SPEED_DEFAULT 3000

//Enter the Arduino pin of the sensor input.  For A0, use 14.  A1, use 15. A2, use 16.  A3, use 17.  A4, use 18.  A5, use 19.  Gates A and B required.  Gates C, D, E, F are optional.
#define GATE_A_PIN 15
#define GATE_B_PIN 16

//Active low means 0V is a gate trigger.  COMMENT OUT for active high (5V = gate is triggered). 
#define ACTIVE_LOW    

//Gate pins are pulled up.  COMMENT OUT to disable pullup resistors.
//#define PULLUP              

//Milliseconds between each gate before test resets. Valid values = 16, 32, 64, 125, 250, 500, 1000, 2000, 4000, 8000
//Note that this will limit the time to output Serial data.  Use BAUD 57600 or higher if MAX_TRANSIT_TIME is less than 64.
#define MAX_TRANSIT_TIME 1000

//END OF SETUP ##############################################################################


//Basic definitions

#define MENU_AB_TEST 0
#define MENU_BA_TEST 1
#define MENU_MAIN 2
#define MENU_ENTER_SETTINGS 3
#define MENU_TRIGGER_ON_OFF 4
#define MENU_TRIGGER_DISTANCE 5
#define MENU_TRIGGER_TIME_OFFSET_0 6
#define MENU_TRIGGER_TIME_OFFSET_1 7
#define MENU_TRIGGER_MAIN 8
#define MENU_SETTINGS_SEPARATION 16
#define MENU_SETTINGS_CALIBRATION 17
#define MENU_SETTINGS_UNITS 18
#define MENU_SETTINGS_MAX_SPEED 19

#define MENU_LAST MENU_TRIGGER_MAIN
#define MENU_LAST_MAIN MENU_TRIGGER_ON_OFF
#define MENU_SETTINGS_FIRST MENU_SETTINGS_SEPARATION
#define MENU_SETTINGS_LAST MENU_SETTINGS_MAX_SPEED

#define EEPROM_ADDRESS_CLOCK 0
#define EEPROM_ADDRESS_BACKLIGHT 2
#define EEPROM_ADDRESS_TRIGGERING 3
#define EEPROM_ADDRESS_UNITS 4
#define EEPROM_ADDRESS_SEPARATION 5
#define EEPROM_ADDRESS_MAX_SPEED 7

#define FPS_CONVERSION 3.28

// include the library code:
  #include <avr/wdt.h>
  #include "defs.h"
  #include <LiquidCrystal.h>
  LiquidCrystal lcd(8, 9, 4, 5, 6, 7);
  #include <EEPROM.h>

//Pins Setup
  byte pinReadValue;
  byte camPin = 0;
  byte gunPin = 0;
  const byte backlightPin = 10;
  const byte inputButtonPin = 14;
  #define BUTTON_INPUT analogRead(inputButtonPin)

//Chronograph Values
  unsigned int clockRate = 1000;
  unsigned int gateSeparation = GATE_SEPARATION_DEFAULT;
  volatile byte ovfCount;
  unsigned long bulletTransitTime;
  unsigned long testMaxSpeed = TEST_MAX_SPEED_DEFAULT;
  float testMinSpeed = TEST_MIN_SPEED;
  unsigned int maximumSpeed = TEST_MAX_SPEED_DEFAULT;
  
//Trigger Setup
  unsigned long _tTimeOffset[2];
  byte _tPin[2];
  unsigned long distToTarget;
  byte _tOn = 0;
  byte triggeringEnabled = 0;
  boolean distanceTrigger = false;
  boolean timeTrigger = false;
  unsigned long triggerDelay;
  unsigned long triggerTime;
  unsigned long triggerComp;
  byte safety = 1;

//Serial Commander
  char serialBuffer[64];
  int sofar;
  byte left;

//LCD Menu
  byte menuPosition = 2;
  byte backlightOn = 1;
  int backlightPwr = 127;
  byte units = 0;



void setup() {
//Begin Serial
  Serial.begin(BAUD);      

//Begin LCD
  lcd.begin(16, 2);
  pinMode(inputButtonPin, INPUT);
  pinMode(backlightPin, OUTPUT);
  backlightPwr = EEPROM.read(EEPROM_ADDRESS_BACKLIGHT);
  analogWrite(backlightPin, backlightPwr);
  units = EEPROM.read(EEPROM_ADDRESS_UNITS);
  const byte microsSymbol[8] = {
    0b00000,
    0b00000,
    0b10001,
    0b10001,
    0b11011,
    0b01101,
    0b00001,
  };
  lcd.createChar(1, microsSymbol);

//Setup chronograph pins
  #ifdef PULLUP
    pinMode(GATE_A_PIN, INPUT_PULLUP);
    pinMode(GATE_B_PIN, INPUT_PULLUP);
  #endif

//Recall triggering state
  if (EEPROM.read(EEPROM_ADDRESS_TRIGGERING) == 1) enableTriggering(); 

//Start communicating with PC
  Serial.println(F("\n\nBallistic Chronograph - READY"));  //Hello world message
  Serial.print(F("Max transit time per gate: "));
  Serial.print(MAX_TRANSIT_TIME);
  Serial.println(F(" ms"));

//Print info to display
  refreshDisplay();
  for (byte i = 0; i < 2; i++){
    _tPin[i] = 255;
  }

//Load clock calibration factor
  clockRate = EEPROMReadint(EEPROM_ADDRESS_CLOCK);
  if (clockRate < 500 || clockRate > 2000) {
    clockRate = 1000;
    EEPROMWriteint(EEPROM_ADDRESS_CLOCK, clockRate);
  }
  gateSeparation = EEPROMReadint(EEPROM_ADDRESS_SEPARATION);
  if (!gateSeparation || gateSeparation == 65535){
    gateSeparation = GATE_SEPARATION_DEFAULT;
    EEPROMWriteint(EEPROM_ADDRESS_SEPARATION, gateSeparation);
  }
  maximumSpeed = EEPROMReadint(EEPROM_ADDRESS_MAX_SPEED);
  if (!maximumSpeed || maximumSpeed == 65535){
    maximumSpeed = TEST_MAX_SPEED_DEFAULT;
    EEPROMWriteint(EEPROM_ADDRESS_MAX_SPEED, maximumSpeed);
  }
}

void loop(){
  getButton();
  runDisplay();
  getCommand();
}


ISR(TIMER1_OVF_vect) {ovfCount++;}

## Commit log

2020-04-20 Update 2020-04-19 MK2 Testing.csv
    [2020-04-19 MK2 Testing.csv]
2020-04-23 Update to 1.1
    Improvements noted in changelog
    [Arduino Mount.STL, ArduinoMount.STL, Ballistic Chronograph MK2 BOM 1.0.csv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]
2020-04-28 LG0 Rev3
    [BOM.csv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]
2020-07-12 Minor corrections to models
    [EmitterCover_double.STL]
2020-07-26 1.2
    Interrupt control improvements

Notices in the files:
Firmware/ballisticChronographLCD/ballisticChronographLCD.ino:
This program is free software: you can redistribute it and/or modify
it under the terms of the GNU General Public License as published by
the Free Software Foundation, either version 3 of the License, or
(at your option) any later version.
